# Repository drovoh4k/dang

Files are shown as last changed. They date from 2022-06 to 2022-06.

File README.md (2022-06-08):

# DANG

## Overview
Debido al Covid, ha surgido una necesidad de controlar la cantidad de personas
que hay en los espacios, es decir, el aforamiento.

Debido a esta problemática surge DANG, un sistema de control de aforo en las
clases de mi universidad. Este sistema permite saber cuánta gente hay dentro de
una clase concreta y mantener una trazabilidad de las aulas en las que ha estado
cualquier persona.

## Architecture
El núcleo del proyecto es un Arduino UNO, el cual se comunica con diferentes
módulos.

* **PN532** --> Módulo que nos permite leer tarjetas RFID
* **SSD1306** --> Display Oled de 64x128 píxeles
* **ESP8206** --> Módulo que nos permite conectarnos a una red Wifi y realizar
  conexiones TCP

El proyecto también consta de una página web, la cual se comunica directamente
con el servidor para mostrar el aforo desde un ordenador o dispositivo móvil.

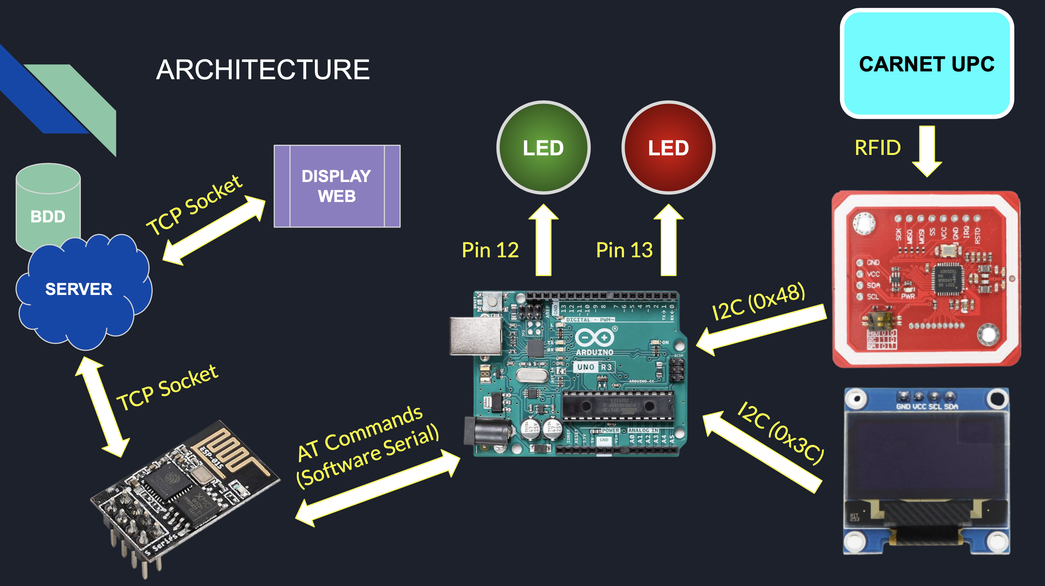
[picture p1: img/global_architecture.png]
Global_architecture


## Prototipe
Las primeras pruebas de software se realizaron sobre protoboard, y una vez se
tenía claro como funcionaba cada módulo y que configuración hardware requería,
se procedió a construir un prototipo.

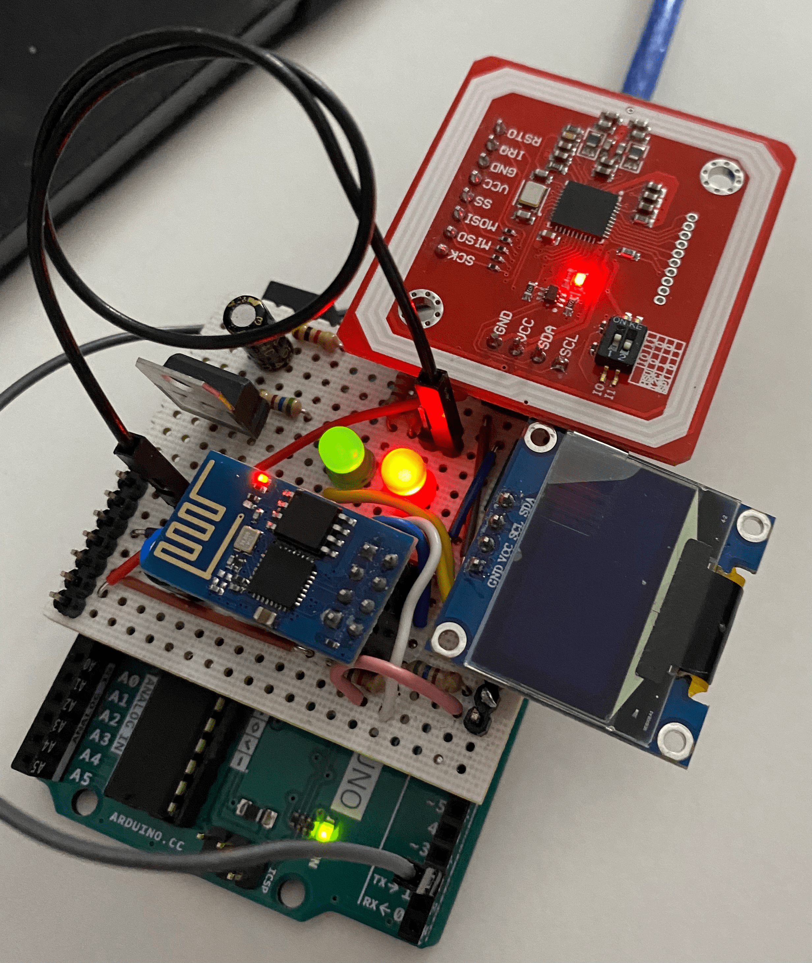
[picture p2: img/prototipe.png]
Prototipe


## PCB
Tras comprobar que el prototipo funcionaba correctamente, se procedió a realizar
la PCB. La cual el esquemático replica completamente el circuito hecho en el
prototipo.

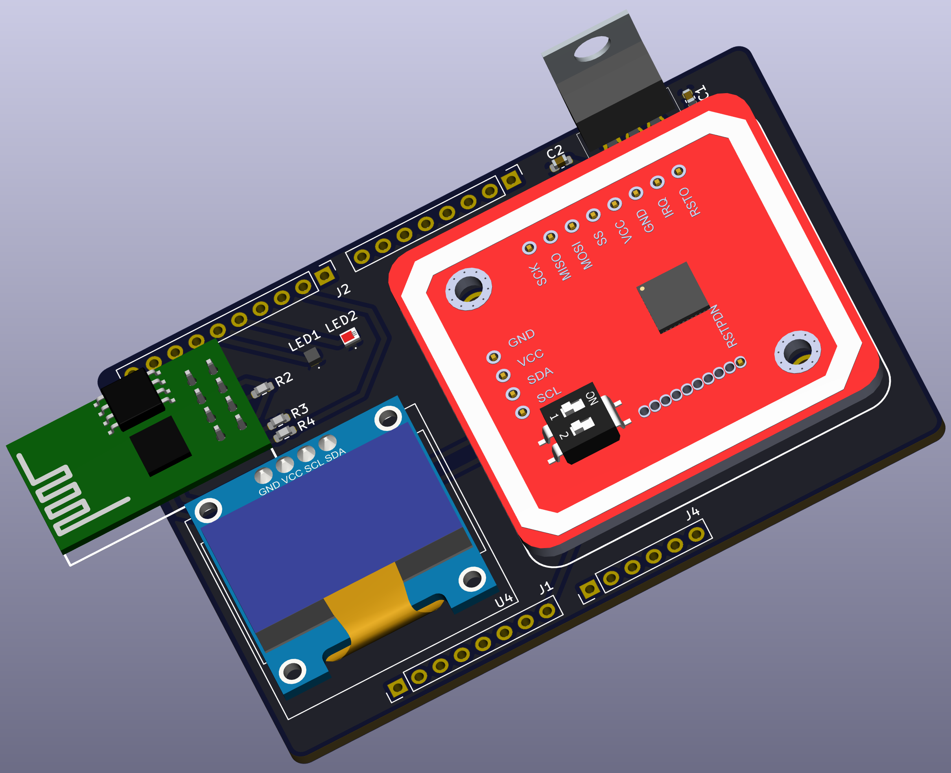
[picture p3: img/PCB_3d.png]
PCB_3d


## Web Page
La web todavia se encuentra en fase de pruebas, pero su finalidad es poder ver
el aforo de cada aula en cada momento.

Hasta el momento su aspecto es el siguiente:

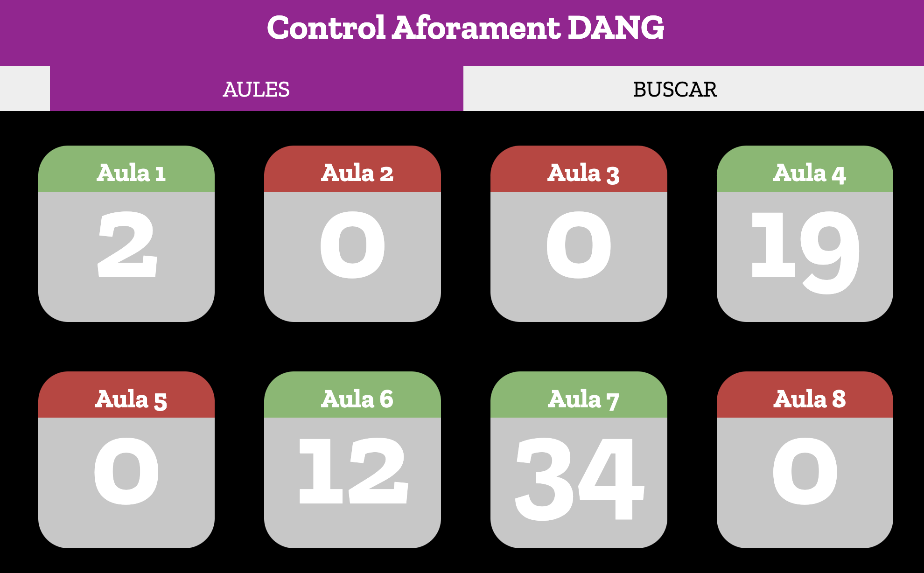
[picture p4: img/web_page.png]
web_page


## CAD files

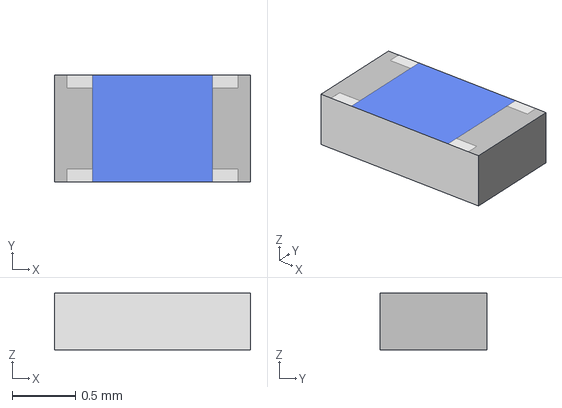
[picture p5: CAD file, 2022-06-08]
PCB/3Ds/R_0603.stp
1.55 x 0.85 x 0.45 mm

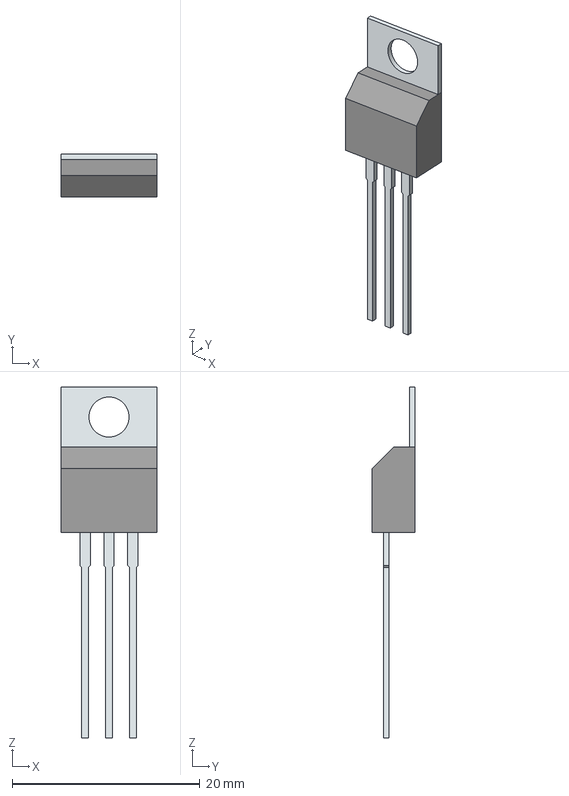
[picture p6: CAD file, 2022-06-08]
PCB/3Ds/LD1117V33.stp
10.2 x 4.60 x 37.4 mm
Tab
PinsArray

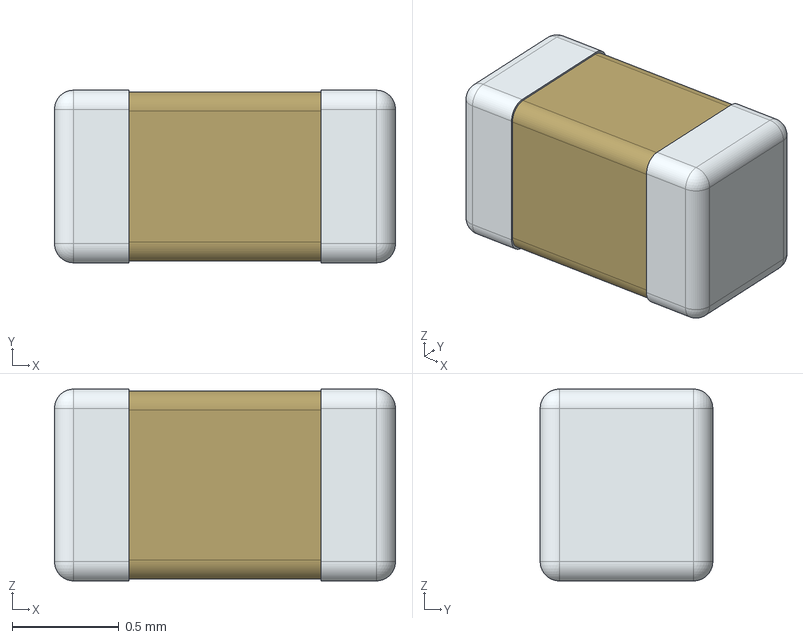
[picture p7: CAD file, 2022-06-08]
PCB/3Ds/C_0603.stp
1.60 x 0.81 x 0.9 mm

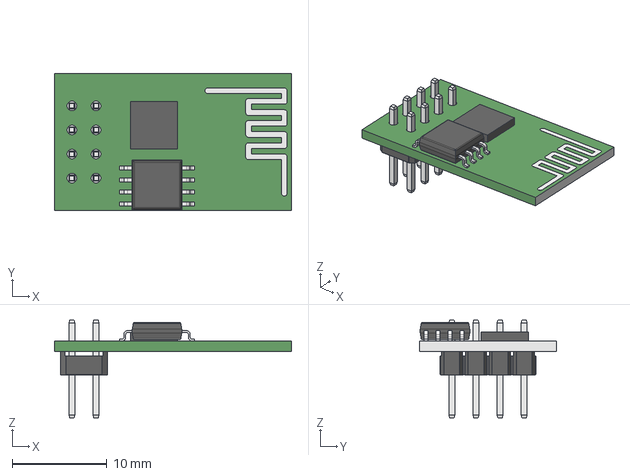
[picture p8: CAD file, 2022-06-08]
PCB/3Ds/ESP8266_ESP01_cp.step
25.0 x 14.5 x 10.3 mm

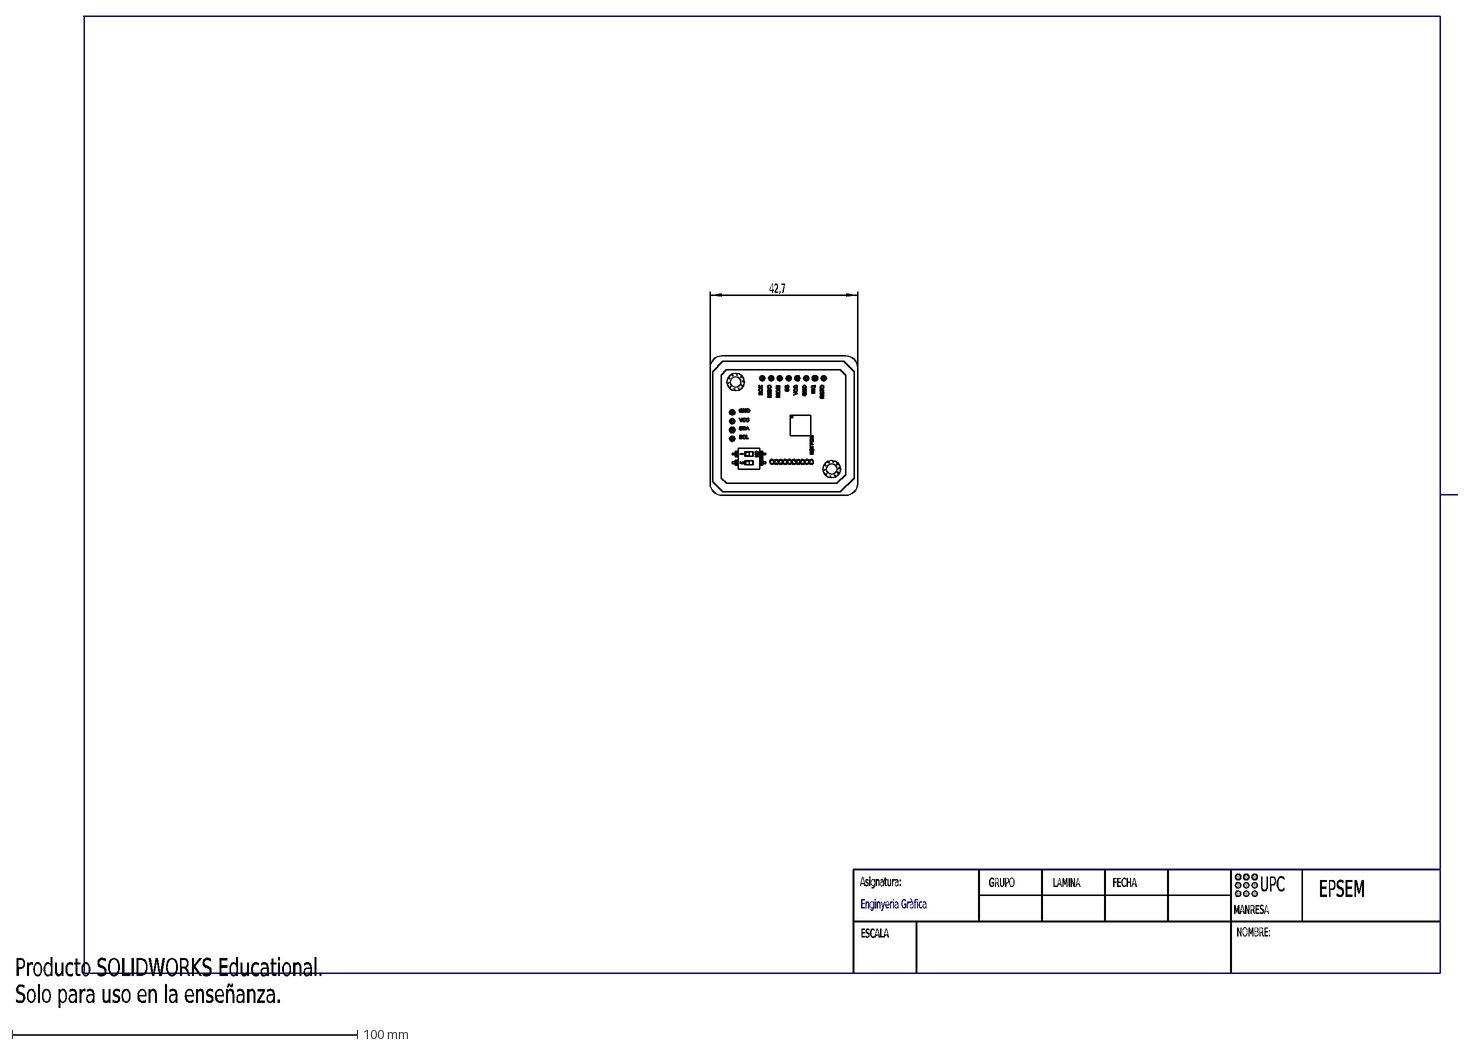
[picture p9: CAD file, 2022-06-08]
PCB/3Ds/PN532_NFC.DXF
Enginyeria Gràfica
NOMBRE:
LAMINA
ESCALA
Asignatura:
GRUPO
UPC
FECHA
EPSEM
MANRESA
42,7
Producto SOLIDWORKS Educational.
Solo para uso en la enseñanza.

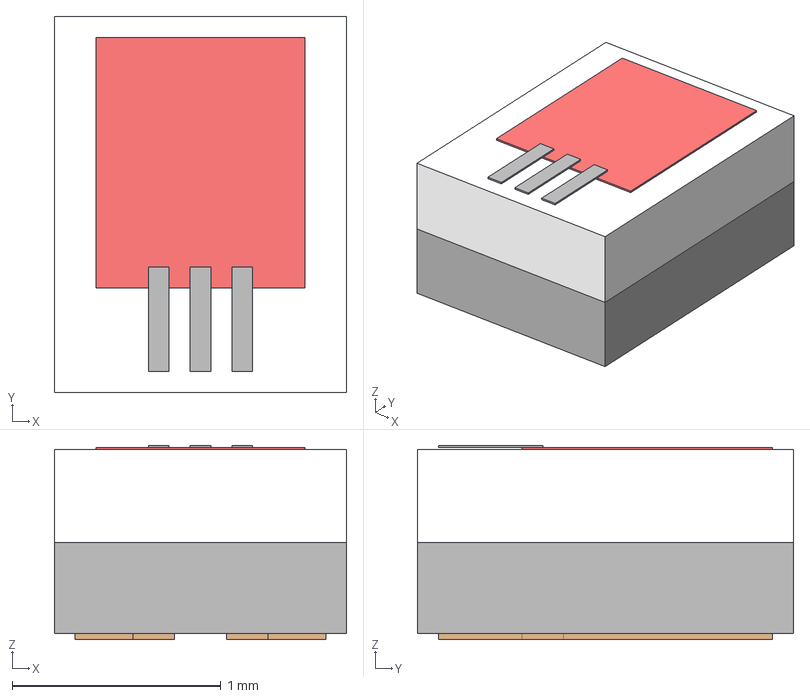
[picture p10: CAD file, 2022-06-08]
PCB/3Ds/L1RX-RED1000000000.stp
1.40 x 1.80 x 0.93 mm
solidBody
solidLead
solidTop
solidBody1
solidBody2

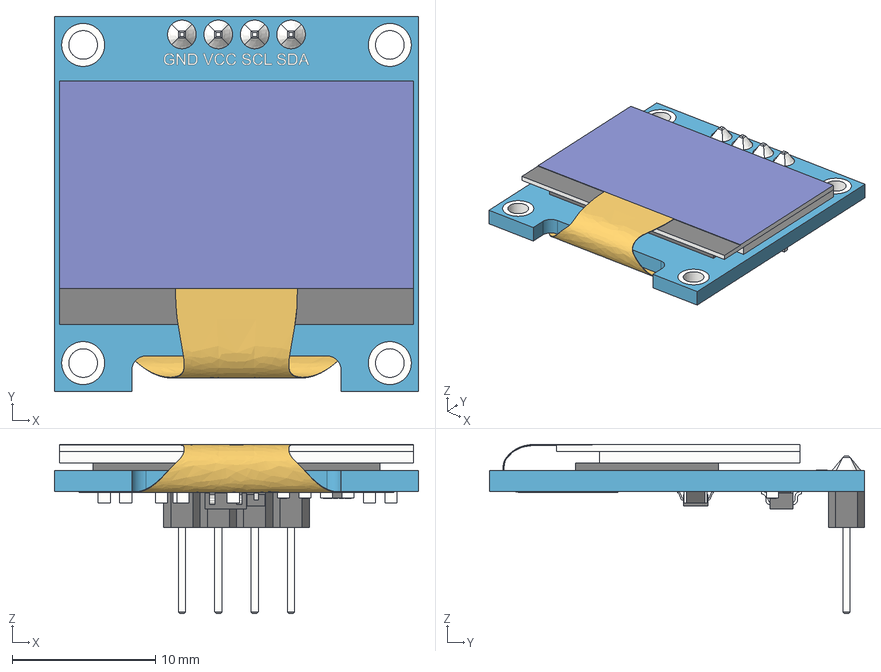
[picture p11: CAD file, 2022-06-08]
PCB/3Ds/SSD1306_OLED_Display(128x64).step
25.4 x 26.2 x 11.8 mm
board
screen
pin_header
soldering
smd_capacitor
smd_capacitor (1)
914_smd_resistor
472_smd_resistor x 3
t4_smd_diode
smd_capacitor (2)
smd_capacitor (3)
smd_capacitor (4)
smd_capacitor (5)
smd_capacitor (6)
472_smd_resistor (1)
SOT-23_XC6206 v3
smd_capacitor (7)
flat_cable

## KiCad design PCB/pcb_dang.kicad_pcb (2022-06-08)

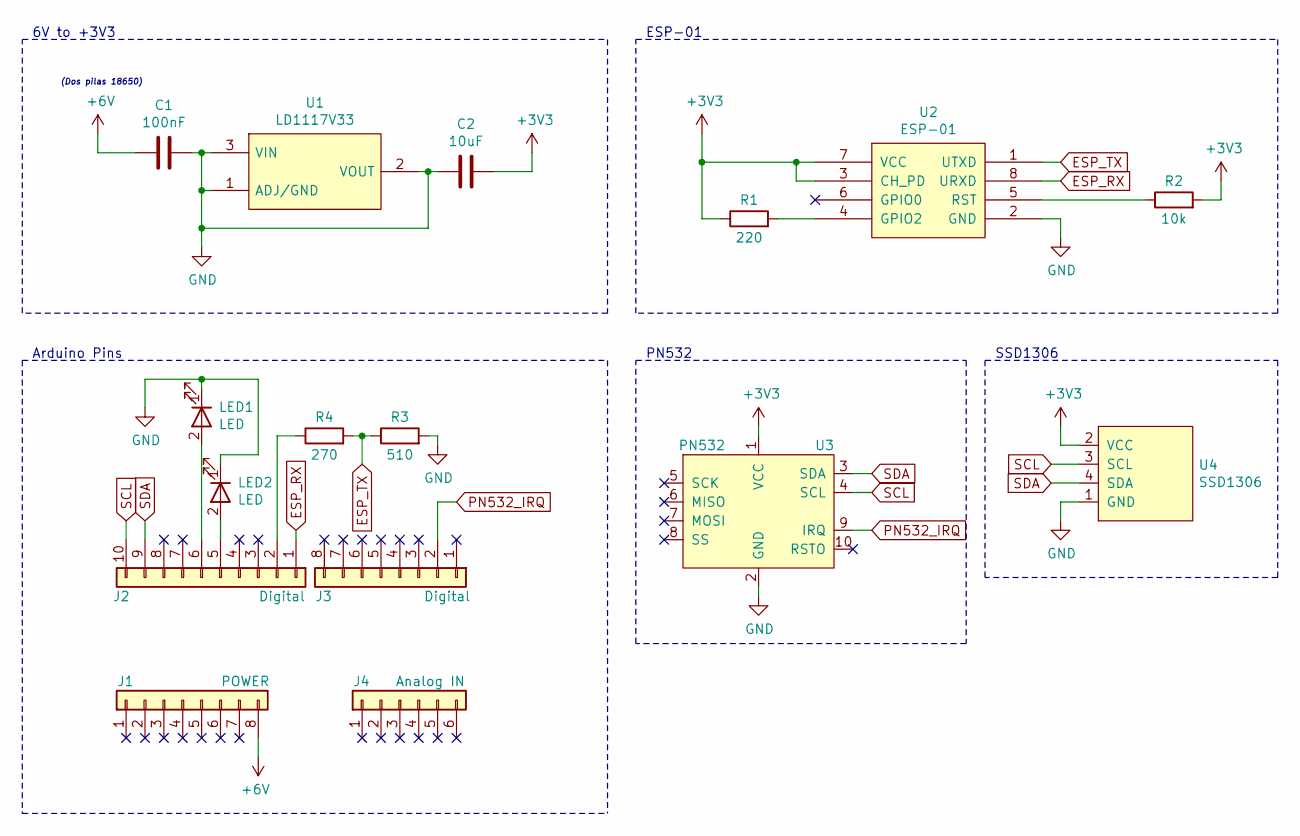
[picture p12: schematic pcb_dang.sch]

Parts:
C1: 100nF; C_0603_1608Metric
C2: 10uF; C_0603_1608Metric
J1: POWER; PinHeader_1x08_P2.54mm_Vertical
J2: Digital; PinHeader_1x10_P2.54mm_Vertical
J3: Digital; PinHeader_1x08_P2.54mm_Vertical
J4: Analog IN; PinHeader_1x06_P2.54mm_Vertical
LED1: LED; L1RXGRN1000000000
LED2: LED; L1RXRED1000000000
R1: 220; R_0603_1608Metric
R2: 10k; R_0603_1608Metric
R3: 510; R_0603_1608Metric
R4: 270; R_0603_1608Metric
U1: LD1117V33
U2: ESP-01
U3: PN532
U4: SSD1306

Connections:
+3V3: C2.1, R1.1, R2.2, U2.3 (CH_PD), U2.7 (VCC), U3.1 (VCC), U4.2 (VCC)
+6V: C1.2, J1.8
ESP_RX: J2.1, U2.8 (URXD)
ESP_TX: R3.1, R4.2, U2.1 (UTXD)
GND: C1.1, C2.2, LED1.1, LED2.1, R3.2, U1.1 (ADJ/GND), U1.2 (VOUT), U1.3 (VIN), U2.2 (GND), U3.2 (GND), U4.1 (GND)
unnamed: J2.2, R4.1
unnamed: J2.5, LED2.2
unnamed: J2.6, LED1.2
unnamed: R1.2, U2.4 (GPIO2)
unnamed: R2.1, U2.5 (RST)
PN532_IRQ: J3.2, U3.9 (IRQ)
SCL: J2.10, U3.4 (SCL), U4.3 (SCL)
SDA: J2.9, U3.3 (SDA), U4.4 (SDA)

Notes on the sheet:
(Dos pilas 18650)
6V to +3V3
Arduino Pins
ESP-01
SSD1306
PN532

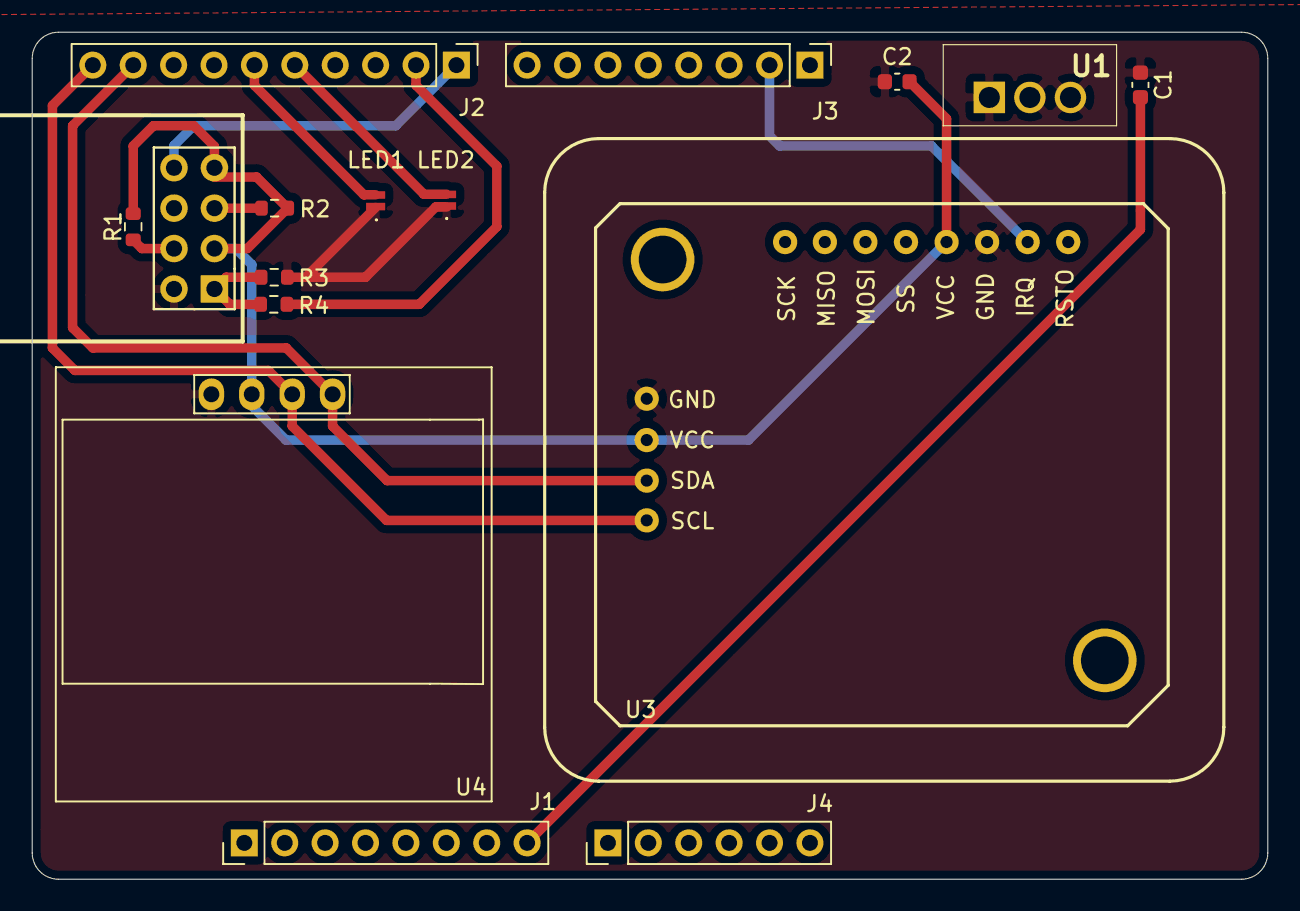
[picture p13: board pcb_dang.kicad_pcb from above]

Board: 2 copper layers, 77.7 x 53.3 mm, 16 parts (0 on the bottom side), 13 nets.

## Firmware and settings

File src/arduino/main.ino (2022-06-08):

/****************************************************************
 *  File: main.ino
 *  Description: Contains main program flow, controlling esp8266,
	diplay and RFID sensor.
 ****************************************************************/

#include "error_handler.h"
#include "db_handler.h"
#include "esp8266.h"
#include "pn532.h"
#include "ssd1306.h"

// Define object to store response
struct response AT_response;
struct response PN532_response;
struct response SSD1306_response;

void setup() {
	// Start comunication with the host computer
	Serial.begin(115200);

	Serial.print(F("\r\n[+] Waiting 5 seconds\r\n\r\n"));
	delay(5000);
	Serial.print(F("\r\n[+] Starting...\r\n\r\n"));

	// Initial ESP8266 setup
	setup_ESP8266();
	//AT_setup(&AT_response,"joldi","12345677");
	AT_setup(&AT_response,"Fibracat_19653","404630b333");

	// Initial SSD1306 setup
	SSD1306_setup(&SSD1306_response);

	delay(500);

	// Initial PN532 setup
	// PN532_setup(&PN532_response);
}


void loop() {
	Serial.print(F("\r\n[+] Loop...\r\n\r\n"));

	//pinMode(12, OUTPUT);
	//pinMode(13, OUTPUT);

	//digitalWrite(12, HIGH);
	//digitalWrite(13, HIGH);

	printafo(&SSD1306_response, 21);

	delay(200);


	// Serial.print("\r\n[+] Waiting for card\r\n");
	// PN532_response.status = -1;
	// while(PN532_response.status == -1) {
	// 	getuid(&PN532_response, 200);
	// }

	// Serial.print(PN532_response.data);

	// String db_send, db_receive, id, aula;

	// id = "2E12AB2C2F";
	// //id = PN532_response.data;
	// aula = "2.2";

	// ESP8266_ping(&AT_response, "192.168.1.28");
	// delay(500);
	
	// ESP8266_tcp_start(&AT_response,"192.168.1.28","10000");

	// delay(500);

	// if (AT_response.status != -1) {
	// 	// Send ID to server
	// 	db_send = db_taul_send(id, aula);
	// 	ESP8266_tcp_data_send(&AT_response, db_send);
	// 	delay(2000);

	// 	// Receive site of server
	// 	ESP8266_tcp_data_receive(&AT_response);
	// 	delay(500);

	// 	db_receive = db_taul_receive(AT_response.data);
	// 	Serial.print(F("\r\n\r\n[+] Site: "));
	// 	Serial.print(db_receive);
	// 	Serial.print(F("\r\n\r\n"));

	// 	// Ask for ocupation
	// 	db_send = db_ocup_send(aula);
	// 	ESP8266_tcp_data_send(&AT_response, db_send);
	// 	delay(2000);
		
	// 	// Receive ocupation
	// 	ESP8266_tcp_data_receive(&AT_response);
	// 	delay(500);

	// 	db_receive = db_ocup_receive(AT_response.data);
	// 	Serial.print(F("\r\n\r\n[+] Ocupation: "));
	// 	Serial.print(db_receive);
	// 	Serial.print(F("\r\n\r\n"));

	// 	ESP8266_tcp_close(&AT_response);
	// 	delay(500);
	// }

	// Wire.endTransmission();

	printafo(&SSD1306_response, 22);
}

// For test -> defwefwot aul-entra-4.3 ewfiwefweif ocup-43 fweiofweifioew

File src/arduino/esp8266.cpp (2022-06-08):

/****************************************************************
 *  File: esp8266.cpp
 *  Description: Contains all functions related to esp8266.
 ****************************************************************/

#include "esp8266.h"

AltSoftSerial altSerial;

void setup_ESP8266() {
	// Start the software serial for communication with the ESP8266
	altSerial.begin(9600);
}

void send_ESP8266(String data) {
	altSerial.print(data);
}

char receive_ESP8266() {
	return altSerial.read();
}

bool available_ESP8266() {
	return altSerial.available();
}

void send_AT(response *res, String data, int timeout, String expected) {
	// Clean ESP8266 buffer
	for (int i=0; i<3; i++) {
		send_ESP8266("AT\r\n");
		delay(150);
	}

	// Clean altSerial buffer
	while ( available_ESP8266() ) {
		char c = receive_ESP8266();
	};

	// Clean data in res
	(*res).data = "";
	(*res).status = 0;

	// Send AT command
	send_ESP8266(data);

	// Store response
	long int time = millis();
	while( (time + timeout) > millis() ) {
		while( available_ESP8266() ) {
			char c = receive_ESP8266();
			(*res).data += c;
		}
		// Añadir un if data contains \r\n exit while
	}

	// Clean altSerial buffer
	while ( available_ESP8266() ) {
		char c = receive_ESP8266();
	};

	// Check for ERROR or OK in data
	if ((*res).data.indexOf("ERROR") != -1) {
		(*res).status = -1;
	} else if ((*res).data.indexOf(expected) != -1) {
		(*res).status = 0;
	} else {
		(*res).status = -1;
	}
}


void AT_setup(response *AT_response, String wifi_name, String wifi_pass) {
	// Disables Echoing
	(*AT_response).status = -1;
	while ((*AT_response).status == -1) {
		send_AT(&(*AT_response), "ATE0\r\n", 500, "OK");

		if ((*AT_response).status == -1) {
			Serial.print(F("\r\n[-] ESP8266 not detected\r\n\r\n"));
		}
	};
	Serial.print(F("\r\n[+] ESP8266 detected\r\n\r\n"));


	// AT+CWMODE_DEF=1 (Set wifi mode to 1.Station)
	(*AT_response).status = -1;
	while ((*AT_response).status == -1) {
		send_AT(&(*AT_response), "AT+CWMODE_DEF=1\r\n", 200, "OK");
	}

	// AT+CWAUTOCONN (Enable Auto Connect AP on power-up)
	(*AT_response).status = -1;
	while ((*AT_response).status == -1) {
		send_AT(&(*AT_response), "AT+CWAUTOCONN=1\r\n", 200, "OK");
	}

	// AT+CIPMUX=0 (Set Single Connection)
	(*AT_response).status = -1;
	while ((*AT_response).status == -1) {
		send_AT((&(*AT_response)), "AT+CIPMUX=0\r\n", 200, "OK");
	}

	// AT+CIPRECVMODE (Set TCP Receive Mode to 1.pasive mode)
	(*AT_response).status = -1;
	while ((*AT_response).status == -1) {
		send_AT((&(*AT_response)), "AT+CIPRECVMODE=1\r\n", 200, "OK");
	}

	// AT+CWJAP_DEF='SSID','PASSWORD' (Join Acces Point)  
	(*AT_response).status = -1;
	while ((*AT_response).status == -1) {
		String at_command = "AT+CWJAP_DEF=\"" + wifi_name + "\",\"" + wifi_pass + "\"\r\n";
		send_AT(&(*AT_response), at_command, 10000, "WIFI GOT IP");

		if ((*AT_response).status == -1) {
			Serial.print(F("\r\n[-] Join Acces Point failed\r\n\r\n"));
		}
	}
	Serial.print(F("\r\n[+] Joined Acces Point\r\n\r\n"));
}

void ESP8266_ping(response *AT_response, String wifi_ip) {
	// AT+PING (Ping Packets)
	int failed_atempts = 0;
	(*AT_response).status = -1;
	while ((*AT_response).status == -1) {
		String at_command = "AT+PING=\"" + wifi_ip + "\"\r\n";
		send_AT(&(*AT_response), at_command, 1000, "OK");

		if ((*AT_response).status == -1) {
			Serial.print(F("\r\n[-] Ping packets failed\r\n\r\n"));

			failed_atempts += 1;
			if (failed_atempts >= 3){
				return;
			}
		}
	}
	Serial.print(F("\r\n[+] Ping Packets OK\r\n\r\n"));
}

void ESP8266_tcp_start(response *AT_response, String wifi_ip, String wifi_port) {
	// AT+CIPSTART (Establishes Connection)
	(*AT_response).status = -1;
	while ((*AT_response).status == -1) {
		String at_command = "AT+CIPSTART=\"TCP\",\"" + wifi_ip + "\"," + wifi_port + "\r\n";
		send_AT(&(*AT_response), at_command, 2000, "OK");

		if ((*AT_response).status == -1) {
			// Check if is already connected
			if((*AT_response).data.indexOf("ALREADY CONNECTED") != -1) {
				break;
			}
			else {
				Serial.print(F("\r\n[-] Open TCP Connection failed\r\n\r\n"));
				return;
			}
		}
	}
	Serial.print(F("\r\n[+] TCP Connection Established\r\n\r\n"));
}

void ESP8266_tcp_data_send(response *AT_response, String data) {
	// AT+CIPSENDBUF (Writes Data into TCP-Send-Buffer)
	(*AT_response).status = -1;
	while ((*AT_response).status == -1) {
		String data_len = String(data.length() - 1);
		
		String at_command = "AT+CIPSENDBUF=" + data_len + "\r\n";
		send_AT(&(*AT_response), at_command, 1000, "");
		send_ESP8266(data);

		if ((*AT_response).status == -1){
			Serial.print("\r\n[-] TCP Data Send failed\r\n\r\n");
			return;
		}
	}
	Serial.print(F("\r\n[+] TCP Data Send\r\n\r\n"));
}

void ESP8266_tcp_data_receive(response *AT_response) {
	// AT+CIPRECVDATA=200 (Get TCP Data in Passive Receive Mode)
	(*AT_response).status = -1;
	while ((*AT_response).status == -1) {
		String at_command = "AT+CIPRECVDATA=200\r\n";
		send_AT((&(*AT_response)), at_command, 2000, "OK");

		if ((*AT_response).status == -1){
			Serial.print("\r\n[-] TCP Data Receive failed\r\n\r\n");
			return;
		}
	}

	Serial.print(F("\r\n[+] TCP Data Received\r\n\r\n"));

	String data = (*AT_response).data;
	
	// Filter data length
	String filter = "CIPRECVDATA";
	int data_len_i1 = data.indexOf(filter) + filter.length() + 1;
	int data_len_i2 = data.indexOf(":", data_len_i1);
	String data_len_s = data.substring(data_len_i1,data_len_i2);
	int data_len = data_len_s.toInt();

	// Filter data
	int data_i1 = data_len_i2 + 1;
	int data_i2 = data_i1 + data_len - 1;
	(*AT_response).data = data.substring(data_i1, data_i2);
}

void ESP8266_tcp_close(response *AT_response) {
	ESP8266_tcp_data_send(&(*AT_response), "close\r\n");

	// AT+CIPCLOSE (Closes Connection)
	// (*AT_response).status = -1;
	// while ((*AT_response).status == -1) {
	// 	String at_command = "AT+CIPCLOSE\r\n";
	//	send_AT(&(*AT_response), at_command, 200, "OK");

	//	if ((*AT_response).status == -1) {
	//		Serial.print(F("\r\n[-] Close TCP Connection failed\r\n\r\n"));
	//		return;
	//	}
	//}
	Serial.print(F("\r\n[+] TCP Connection Closed\r\n\r\n"));
}

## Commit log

2022-06-08 Arduino code added
2022-06-08 PCB project added
    [C_0603.stp, ESP8266_ESP01_cp.step, L1RX-GRN1000000000.stp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]
